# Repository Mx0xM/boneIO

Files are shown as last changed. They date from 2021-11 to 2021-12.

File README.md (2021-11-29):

# Project description

BonePic
BoneDiagram

`BoneIO` is a compact IO controller for home automation. Main features of this controller are

- Compact size (27x11x6)cm - 15 DIN modules
- DIN rail compatibility
- Low price
- Open HSP (See below)

# Technical details of v0.2

InputBoard

<<<<<<< HEAD

=======
>>>>>>> parent of 0485a88 (Update README.md)
- 52 digital inputs
- 7 analog to digital converters
- i2c
- rs485
- OLED display
- user switch
- 24V PSU input
- ADC VDD output
- 12-48V external PSU for digital inputs
- jumper to switch between internal and external PSU for inputs
- jumper to switch between vcc and gnd input control

RelayBoard24x16

- 24 relays (230V/16A) max current 5A* (10A* tinned traces, 16A* bridged 1,5 mm²) *everything needs to be verified
- temp sensor

RelayBoard32x5

- 32 relays (230V/5A)
- temp sensor

# Open HSP

`BoneIO` is an Open HSP initiative where everything is open on [GPL-3.0 License](https://github.com/maciejk1984/boneIO/blob/main/LICENSE)

- H (Hardware) stands for projects of electronic boards which you can print yourself
- S (Software) stands for ready to use firmware you can use on printed hardware
- P (Printables) stands for cases and other plastic elements you can print on a 3D printer and use with our hardware

With all elements in place, you can assemble a complete device. You can use it as-is or fork and modify it for your needs.

# Contribution

If you want to contribute to the project here are the rules:

1. First watch this short training: [How to use repo](https://www.youtube.com/watch?v=aY7B_t2UZy4)
2. When you have something to discuss first check out our [Team chat](https://discord.gg/PsrXEz9CBp)
3. When you have a specific problem/feature to report add new [issue](https://github.com/maciejk1984/boneIO/issues). `Remember to report single topic in one issue`. If you have complex topic try split it to more **precise** topics.
4. When you want change something in the repository use your **Fork** and make new **Pull Request** (See [Working with repository](.docs/github.md) (Polish))
5. You can also monitor our [Facebook group](https://www.facebook.com/groups/boneio)

# Documentation

- [Working with repository](.docs/github.md) (Polish)
- Youtube
  - [Project introduction](https://www.youtube.com/watch?v=_EIppBDZWvk) (Polish)
  - [Case introduction](https://www.youtube.com/watch?v=QjhMvNn7mG0) (Polish)
  - [Project status - 17.10.2021](https://www.youtube.com/watch?v=6J2S1L4vNMw) (Polish) 

# Photos of v0.1

Github

Github

Github

Github

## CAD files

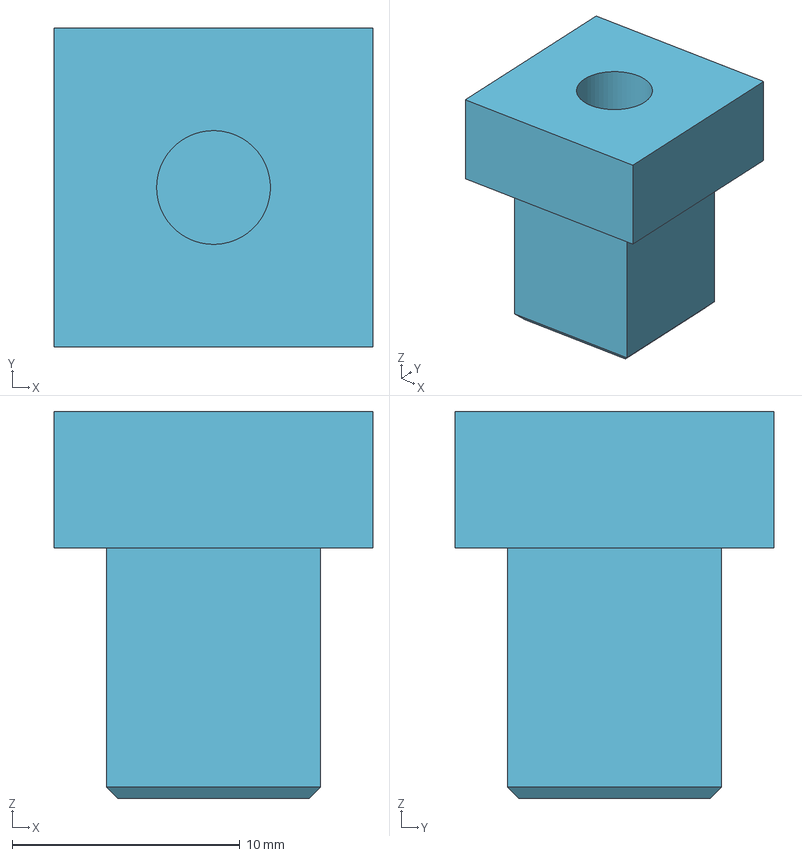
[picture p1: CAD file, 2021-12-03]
Case/boneIO-button.stp
14.0 x 14.0 x 17.0 mm

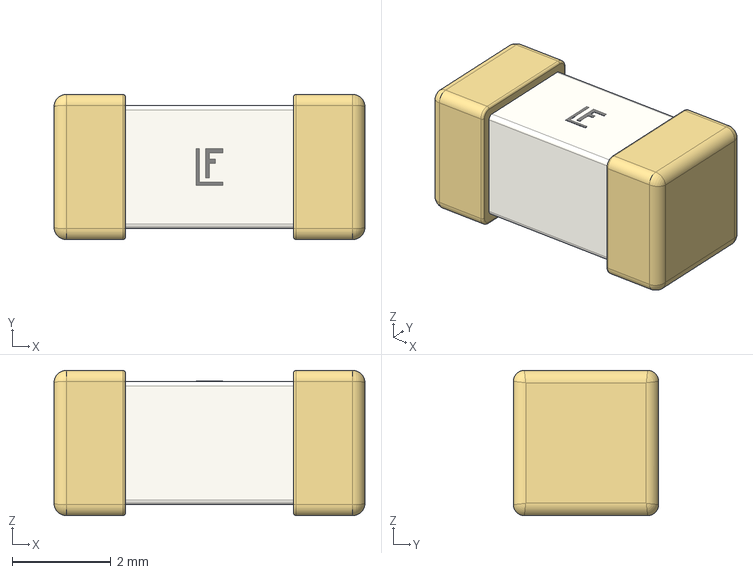
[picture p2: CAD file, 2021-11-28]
Circuit/boneIO - input board/3D_model/FUSE LTL-451.stp
6.30 x 2.94 x 2.94 mm

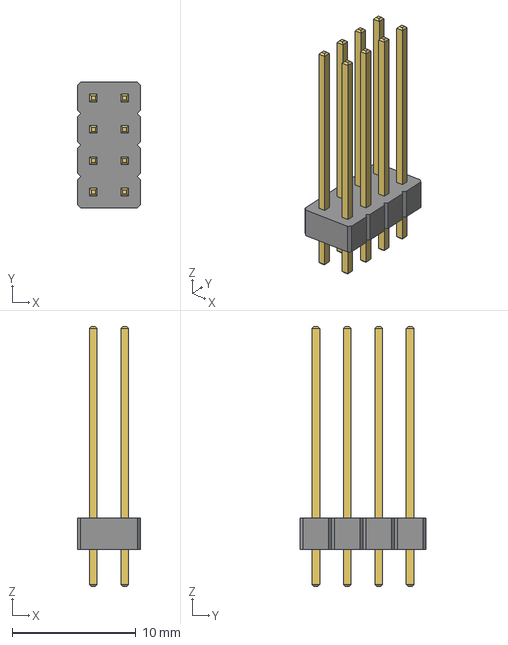
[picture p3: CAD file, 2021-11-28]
Circuit/boneIO - relay board 24x16A/3D_model/PH80DS-21.stp
5.08 x 10.2 x 21.0 mm

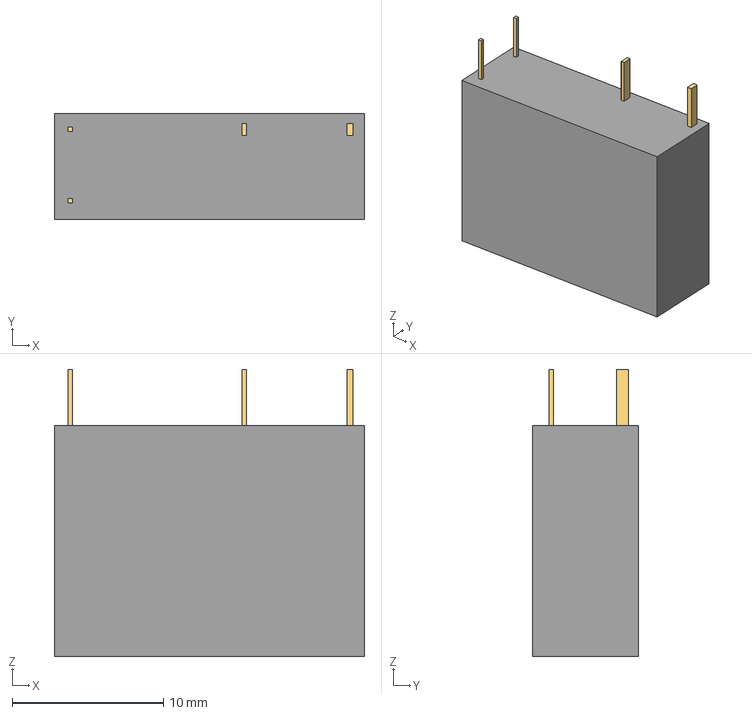
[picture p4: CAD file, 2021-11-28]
Circuit/boneIO - relay board 32x5A/HF46/HF46F.step
20.5 x 7.00 x 19.0 mm

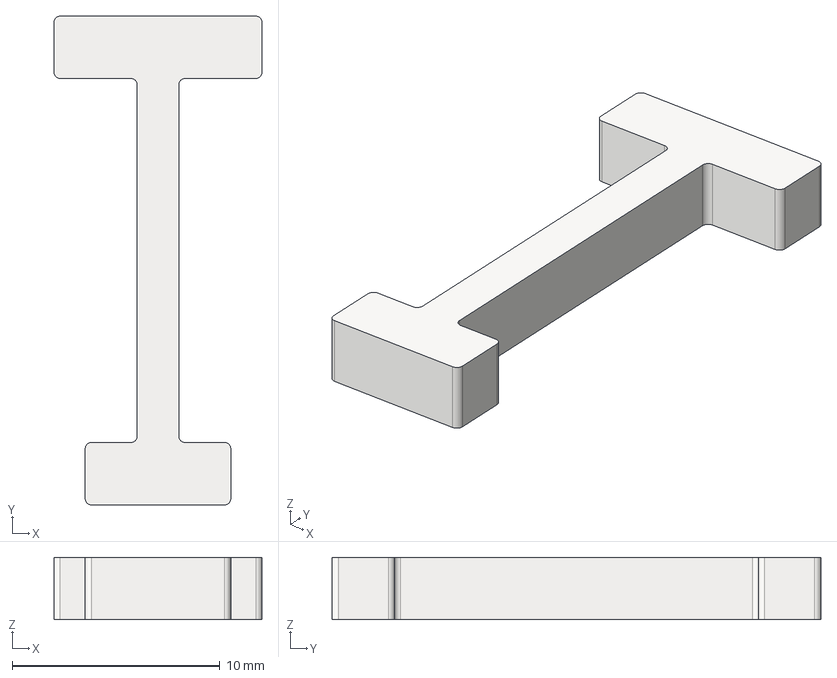
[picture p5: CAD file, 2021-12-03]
Case/boneIO-lock-pin.stp
10.0 x 23.5 x 3.00 mm

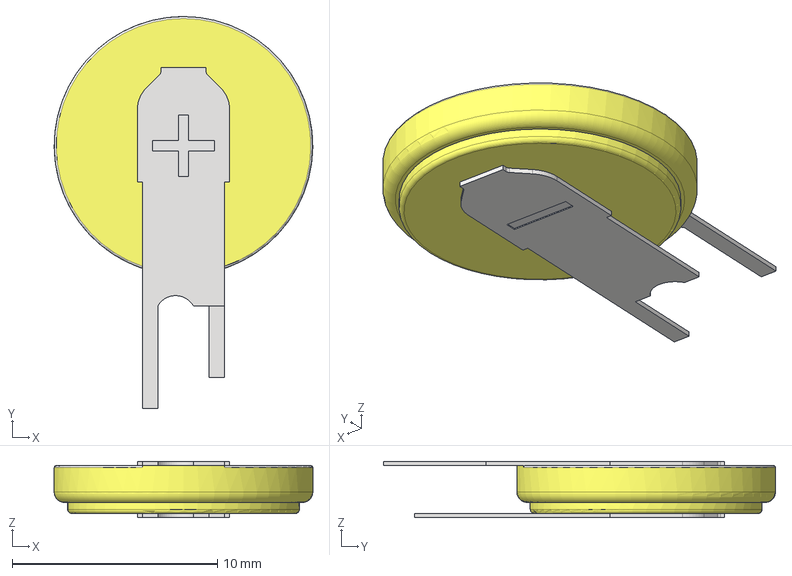
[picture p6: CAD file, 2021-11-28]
Circuit/boneIO - input board/3D_model/CR1220_VCNK.stp
12.6 x 19.1 x 2.74 mm

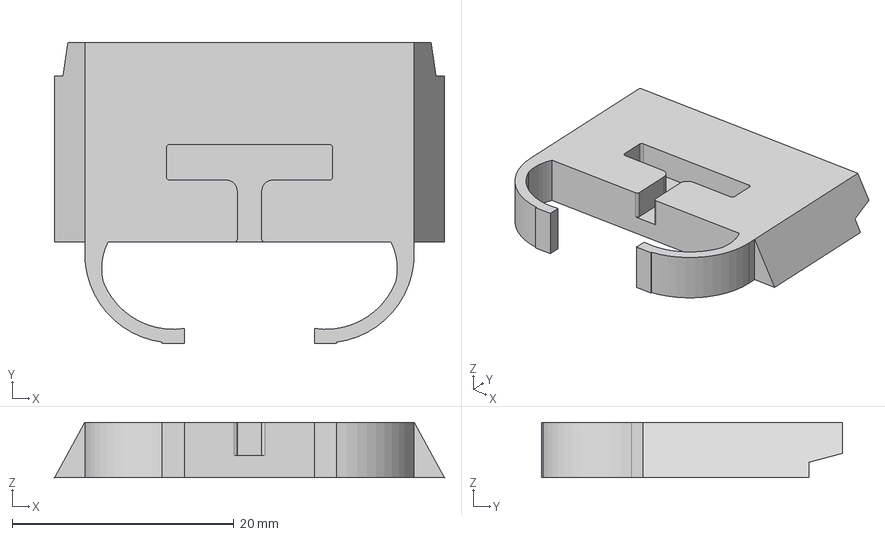
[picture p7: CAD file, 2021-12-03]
Case/boneIO-bottom-clips.stp
35.2 x 27.1 x 5.00 mm

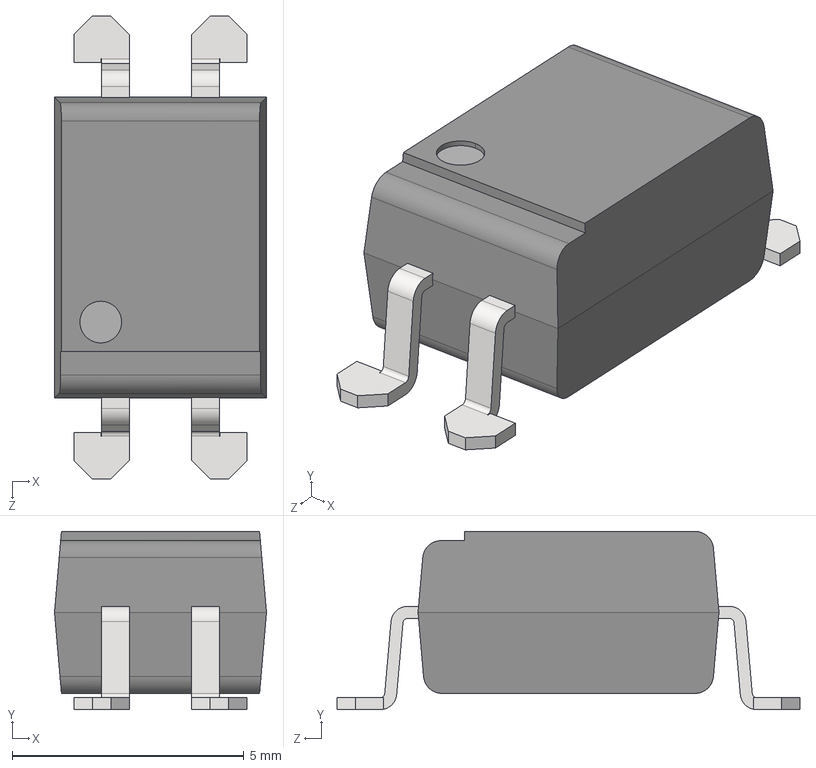
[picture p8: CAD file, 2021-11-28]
Circuit/boneIO - input board/3D_model/PC817.STEP
4.58 x 3.85 x 10.0 mm
PC817 Body
Gullwing Pin
Gullwing Pin_MIR
Gullwing Pin_MIR1
Gullwing Pin_MIR_MIR

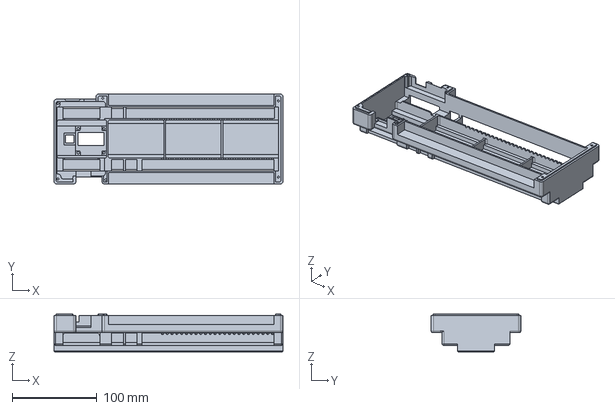
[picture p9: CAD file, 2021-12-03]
Case/boneIO-case-front.stp
270.0 x 106.0 x 44.5 mm

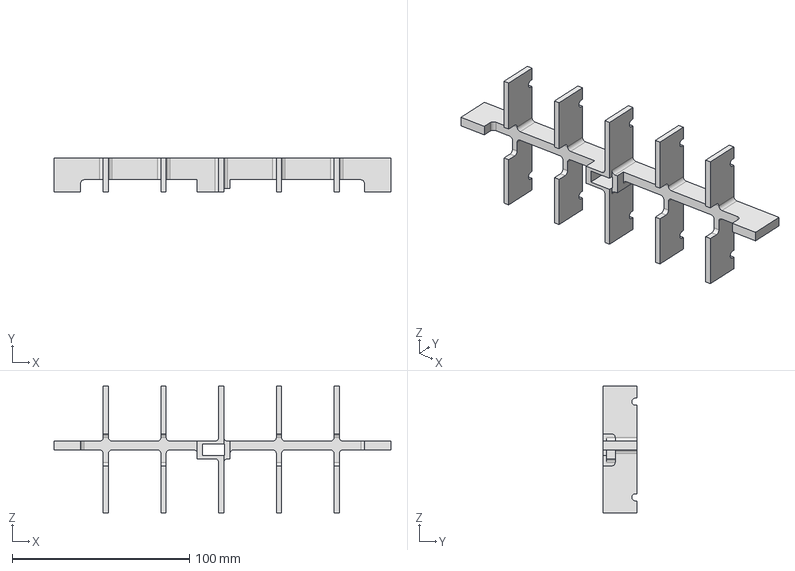
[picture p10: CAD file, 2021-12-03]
Case/boneIO-button-distance-relay-24x16A v0.2.stp
190.0 x 19.4 x 71.5 mm

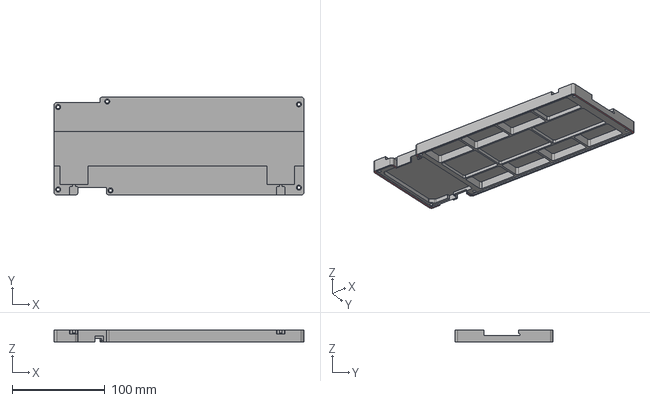
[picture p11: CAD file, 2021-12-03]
Case/boneIO-case-back.stp
270.0 x 106.0 x 12.5 mm

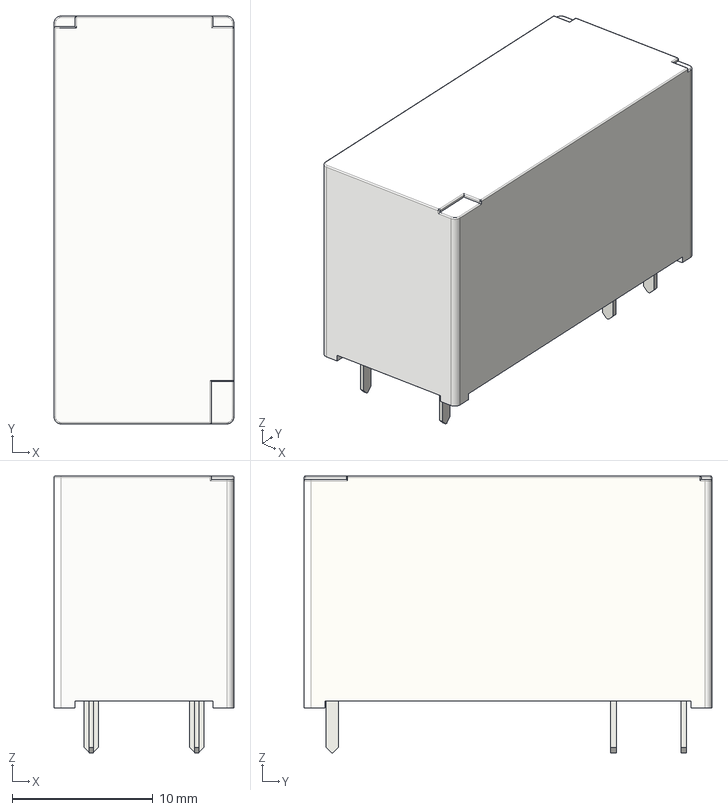
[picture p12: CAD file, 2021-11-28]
Circuit/boneIO - relay board 24x16A/3D_model/RM852011351005_1.step
12.8 x 29.0 x 19.7 mm

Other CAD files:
Case/boneIO-button-distance-relay-32x5A v0.2.stp
Case/boneIO-bottom-clips.stl
Case/boneIO-button-distance-relay-24x16A v0.2.stl
Case/boneIO-button-distance-relay-32x5A v0.2.stl
Case/boneIO-button.stl
Case/boneIO-case-back.stl
Case/boneIO-case-front.stl
Case/boneIO-lock-pin.stl

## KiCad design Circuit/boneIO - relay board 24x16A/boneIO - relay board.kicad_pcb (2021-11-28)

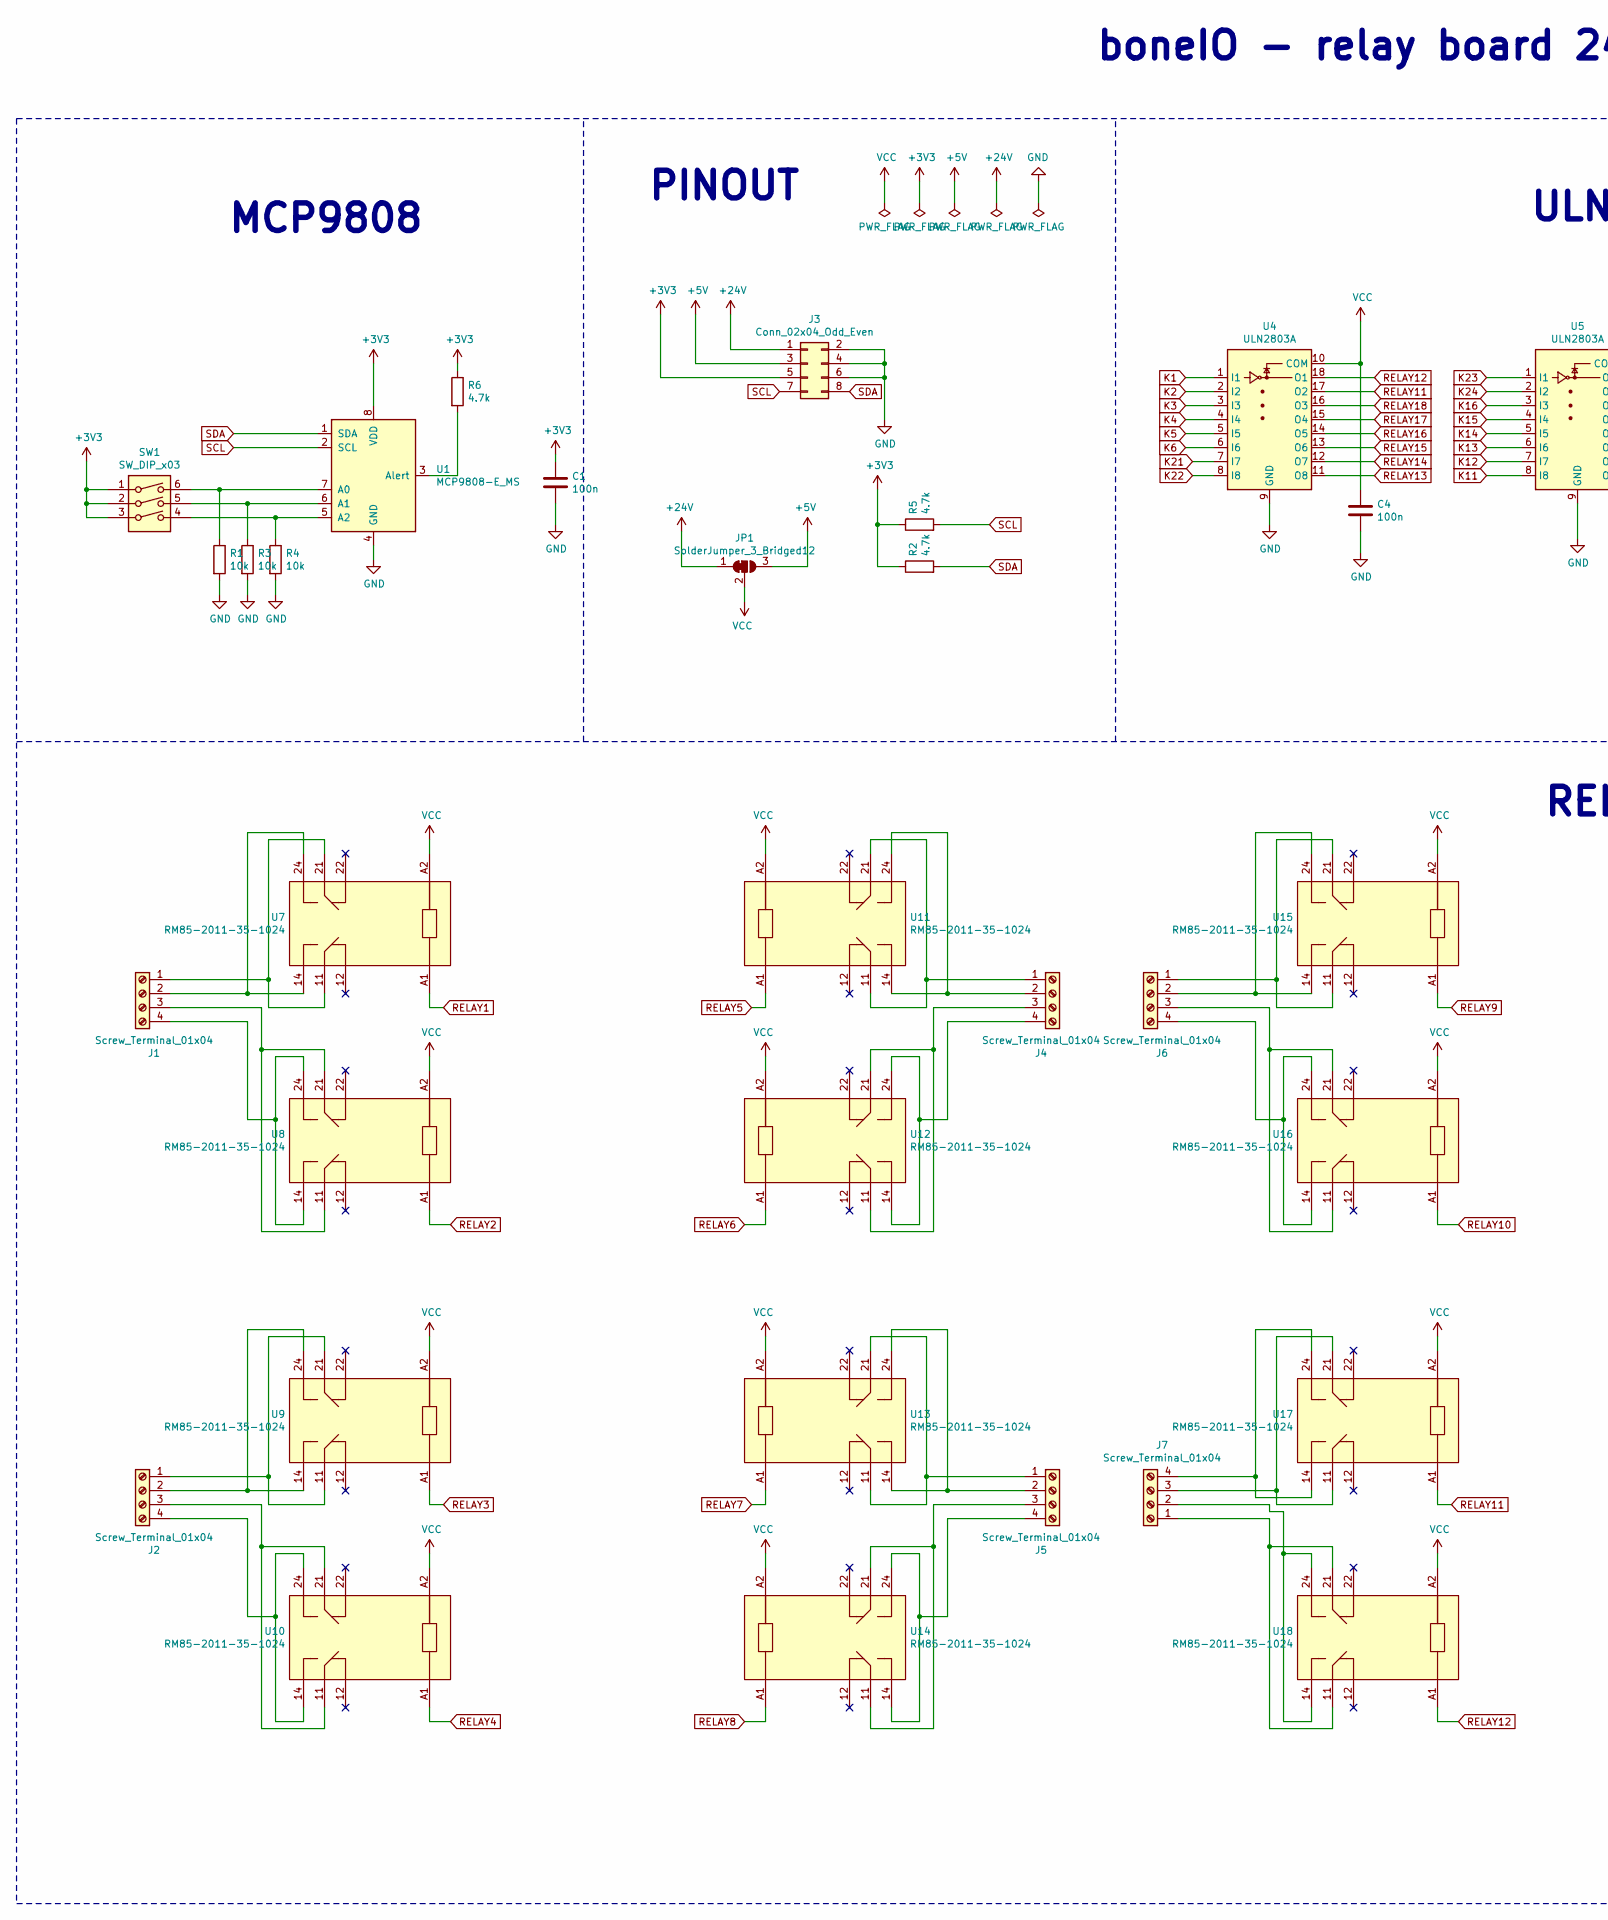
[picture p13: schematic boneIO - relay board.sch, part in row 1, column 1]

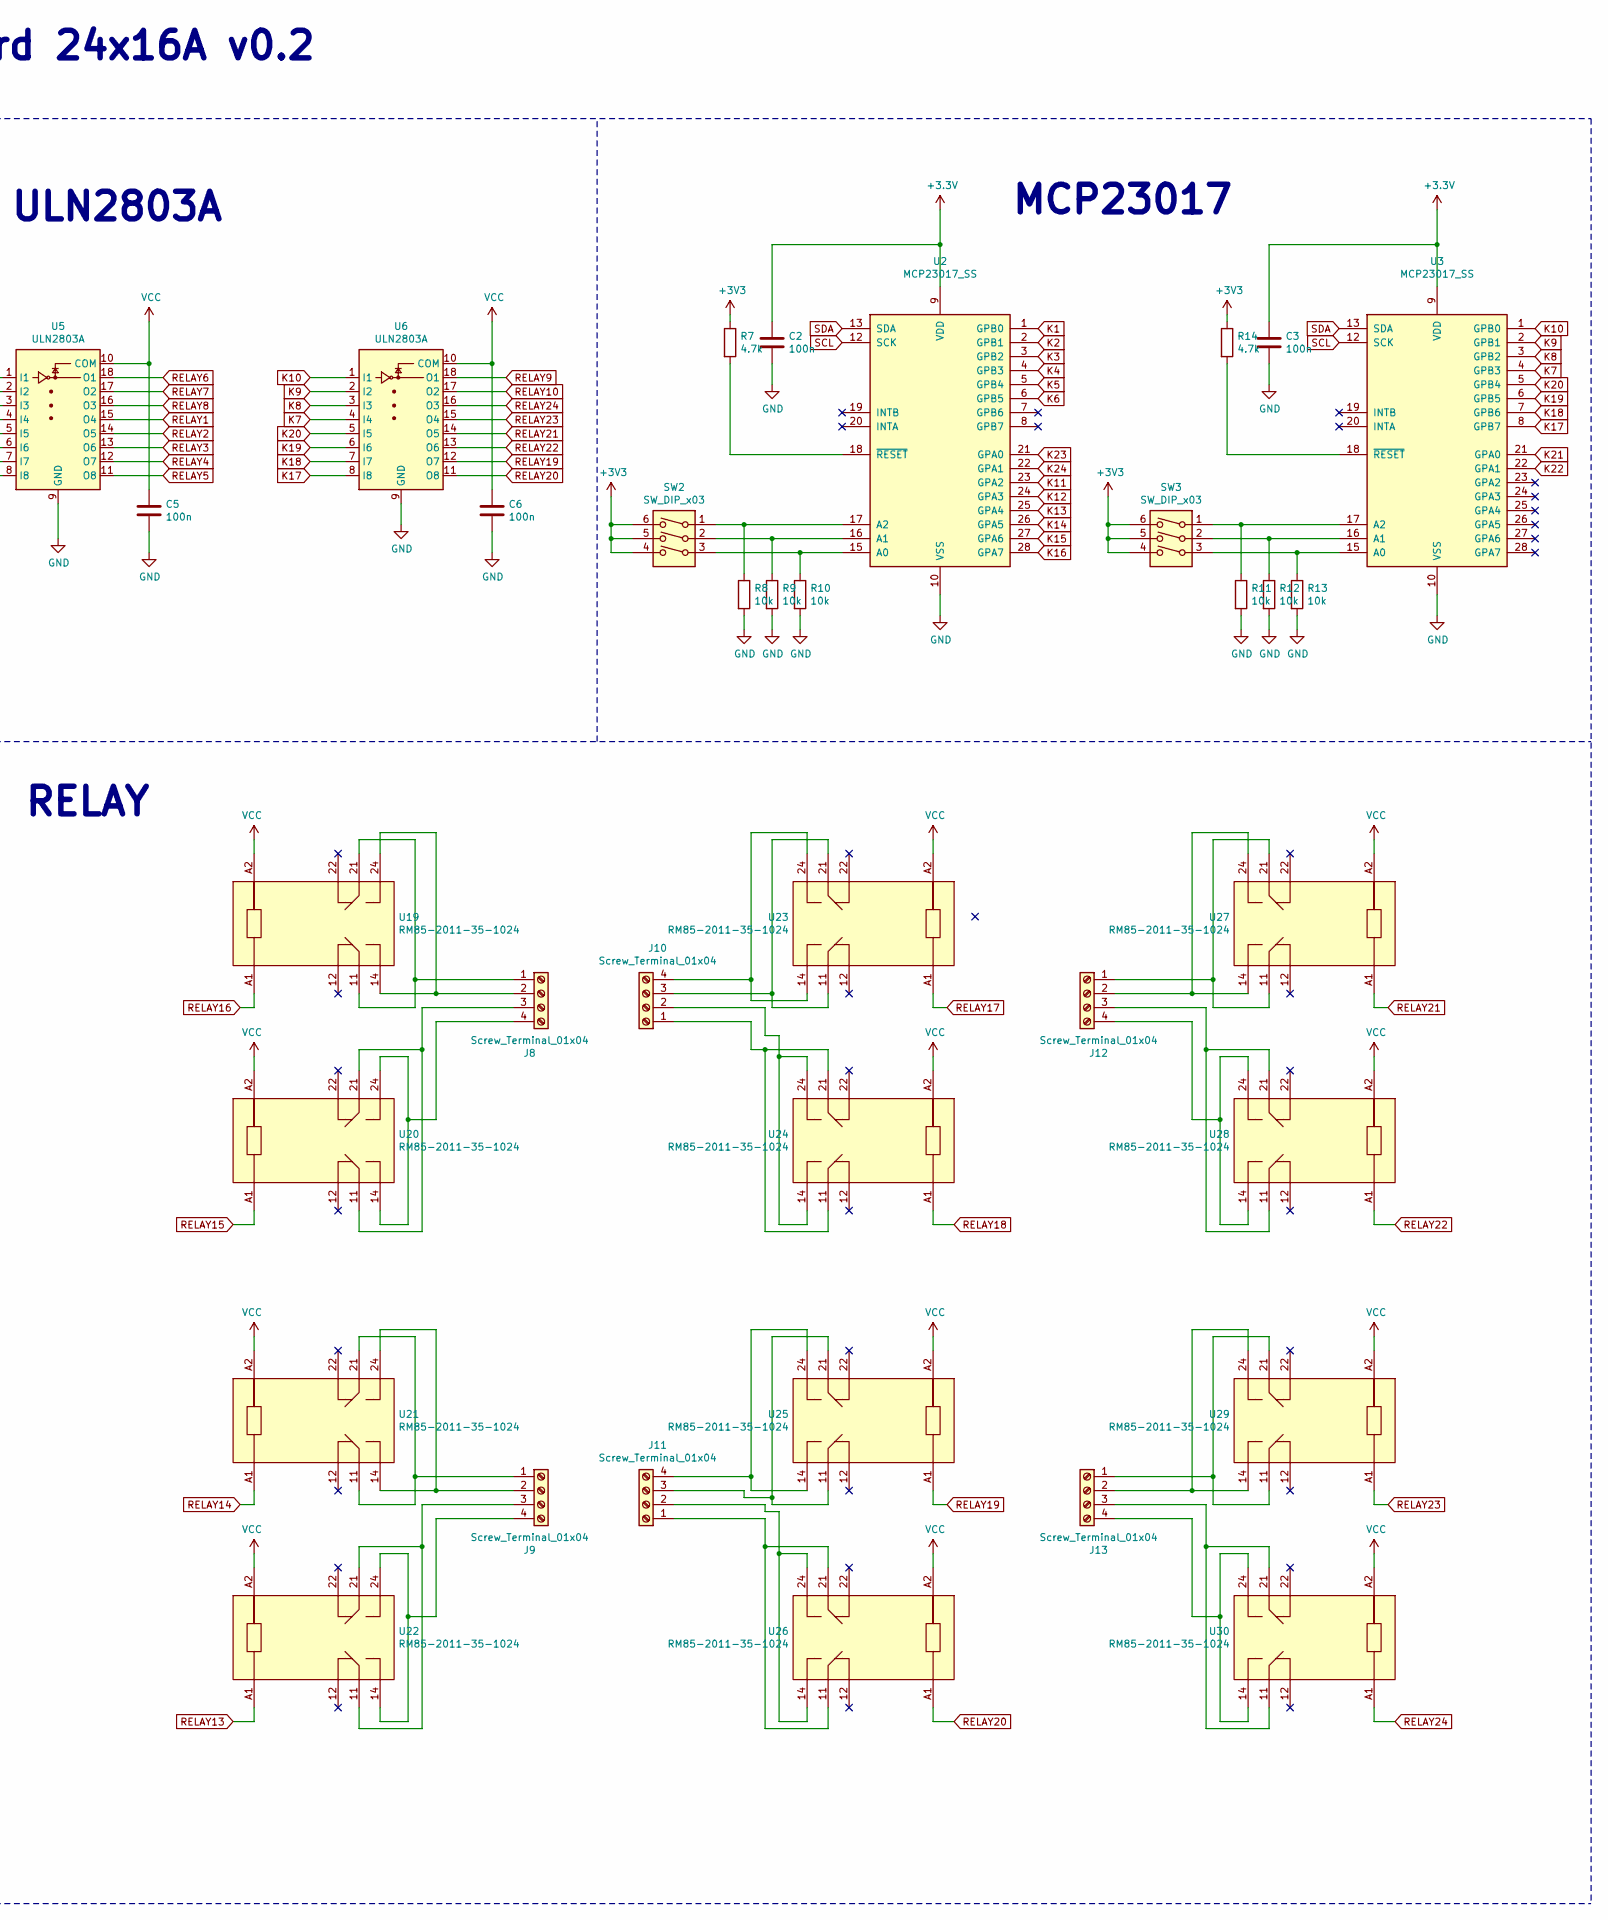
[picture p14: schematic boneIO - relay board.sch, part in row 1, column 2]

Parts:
C1, C2, C3, C4, C5, C6: 100n; C_0603_1608Metric
J1, J2, J4, J5, J6, J7, J8, J9, J10, J11, J12, J13: Screw_Terminal_01x04; PhoenixContact_GMSTBA_2,5_4-G_1x04_P7.50mm_Horizontal
J3: Conn_02x04_Odd_Even; PinHeader_2x04_P2.54mm_Vertical
JP1: SolderJumper_3_Bridged12; SolderJumper-3_P1.3mm_Bridged12_RoundedPad1.0x1.5mm
R1, R3, R4, R8, R9, R10, R11, R12, R13: 10k; R_0603_1608Metric
R2, R5, R6, R7, R14: 4.7k; R_0603_1608Metric
SW1, SW2, SW3: SW_DIP_x03; SW_DIP_SPSTx03_Slide_KingTek_DSHP03TJ_W5.25mm_P1.27mm_JPin
U1: MCP9808-E_MS; SOP65P490X110-8N
U2, U3: MCP23017_SS; SSOP-28_5.3x10.2mm_P0.65mm
U4, U5, U6: ULN2803A; SOIC-18W_7.5x11.6mm_P1.27mm
U7, U8, U9, U10, U11, U12, U13, U14, U15, U16, U17, U18, U19, U20, U21, U22, U23, U24, U25, U26, U27, U28, U29, U30: RM85-2011-35-1024; RM852011351024

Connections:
+5V: J3.3, JP1.3 (B)
+24V: J3.1, JP1.1 (A)
GND: C1.2, C2.2, C3.2, C4.2, C5.2, C6.2, J3.2, J3.4, J3.6, R1.2, R3.2, R4.2, R8.2, R9.2, R10.2, R11.2, R12.2, R13.2, U1.4 (GND), U2.10 (VSS), U3.10 (VSS), U4.9 (GND), U5.9 (GND), U6.9 (GND)
K1: U2.1 (GPB0), U4.1 (I1)
K2: U2.2 (GPB1), U4.2 (I2)
K3: U2.3 (GPB2), U4.3 (I3)
K4: U2.4 (GPB3), U4.4 (I4)
K5: U2.5 (GPB4), U4.5 (I5)
K6: U2.6 (GPB5), U4.6 (I6)
K7: U3.4 (GPB3), U6.4 (I4)
K8: U3.3 (GPB2), U6.3 (I3)
K9: U3.2 (GPB1), U6.2 (I2)
K10: U3.1 (GPB0), U6.1 (I1)
K11: U2.23 (GPA2), U5.8 (I8)
K12: U2.24 (GPA3), U5.7 (I7)
K13: U2.25 (GPA4), U5.6 (I6)
K14: U2.26 (GPA5), U5.5 (I5)
K15: U2.27 (GPA6), U5.4 (I4)
K16: U2.28 (GPA7), U5.3 (I3)
K17: U3.8 (GPB7), U6.8 (I8)
K18: U3.7 (GPB6), U6.7 (I7)
K19: U3.6 (GPB5), U6.6 (I6)
K20: U3.5 (GPB4), U6.5 (I5)
K21: U3.21 (GPA0), U4.7 (I7)
K22: U3.22 (GPA1), U4.8 (I8)
K23: U2.21 (GPA0), U5.1 (I1)
K24: U2.22 (GPA1), U5.2 (I2)
unnamed: J1.1, U7.11, U7.21
unnamed: J1.2, U7.14, U7.24
unnamed: J1.3, U8.11, U8.21
unnamed: J1.4, U8.14, U8.24
unnamed: J2.1, U9.11, U9.21
unnamed: J2.2, U9.14, U9.24
unnamed: J2.3, U10.11, U10.21
unnamed: J2.4, U10.14, U10.24
unnamed: J4.1, U11.11, U11.21
unnamed: J4.2, U11.14, U11.24
unnamed: J4.3, U12.11, U12.21
unnamed: J4.4, U12.14, U12.24
unnamed: J5.1, U13.11, U13.21
unnamed: J5.2, U13.14, U13.24
unnamed: J5.3, U14.11, U14.21
unnamed: J5.4, U14.14, U14.24
unnamed: J6.1, U15.11, U15.21
unnamed: J6.2, U15.14, U15.24
unnamed: J6.3, U16.11, U16.21
unnamed: J6.4, U16.14, U16.24
unnamed: J7.1, U18.11, U18.21
unnamed: J7.2, U18.14, U18.24
unnamed: J7.3, U17.11, U17.21
unnamed: J7.4, U17.14, U17.24
unnamed: J8.1, U19.11, U19.21
unnamed: J8.2, U19.14, U19.24
unnamed: J8.3, U20.11, U20.21
unnamed: J8.4, U20.14, U20.24
unnamed: J9.1, U21.11, U21.21
unnamed: J9.2, U21.14, U21.24
unnamed: J9.3, U22.11, U22.21
unnamed: J9.4, U22.14, U22.24
unnamed: J10.1, U24.11, U24.21
unnamed: J10.2, U24.14, U24.24
unnamed: J10.3, U23.11, U23.21
unnamed: J10.4, U23.14, U23.24
unnamed: J11.1, U26.11, U26.21
unnamed: J11.2, U26.14, U26.24
unnamed: J11.3, U25.11, U25.21
unnamed: J11.4, U25.14, U25.24
unnamed: J12.1, U27.11, U27.21
unnamed: J12.2, U27.14, U27.24
unnamed: J12.3, U28.11, U28.21
unnamed: J12.4, U28.14, U28.24
unnamed: J13.1, U29.11, U29.21
unnamed: J13.2, U29.14, U29.24
unnamed: J13.3, U30.11, U30.21
unnamed: J13.4, U30.14, U30.24
unnamed: R1.1, SW1.6, U1.7 (A0)
unnamed: R3.1, SW1.5, U1.6 (A1)
unnamed: R4.1, SW1.4, U1.5 (A2)
unnamed: R6.2, U1.3 (Alert)
unnamed: R7.2, U2.18 (~RESET~)
unnamed: R8.1, SW2.1, U2.17 (A2)
unnamed: R9.1, SW2.2, U2.16 (A1)
unnamed: R10.1, SW2.3, U2.15 (A0)
unnamed: R11.1, SW3.1, U3.17 (A2)
unnamed: R12.1, SW3.2, U3.16 (A1)
unnamed: R13.1, SW3.3, U3.15 (A0)
unnamed: R14.2, U3.18 (~RESET~)
RELAY1: U5.15 (O4), U7.A1
RELAY2: U5.14 (O5), U8.A1
RELAY3: U5.13 (O6), U9.A1
RELAY4: U5.12 (O7), U10.A1
RELAY5: U5.11 (O8), U11.A1
RELAY6: U5.18 (O1), U12.A1
RELAY7: U5.17 (O2), U13.A1
RELAY8: U5.16 (O3), U14.A1
RELAY9: U6.18 (O1), U15.A1
RELAY10: U6.17 (O2), U16.A1
RELAY11: U4.17 (O2), U17.A1
RELAY12: U4.18 (O1), U18.A1
RELAY13: U4.11 (O8), U22.A1
RELAY14: U4.12 (O7), U21.A1
RELAY15: U4.13 (O6), U20.A1
RELAY16: U4.14 (O5), U19.A1
RELAY17: U4.15 (O4), U23.A1
RELAY18: U4.16 (O3), U24.A1
RELAY19: U6.12 (O7), U25.A1
RELAY20: U6.11 (O8), U26.A1
RELAY21: U6.14 (O5), U27.A1
RELAY22: U6.13 (O6), U28.A1
RELAY23: U6.15 (O4), U29.A1
RELAY24: U6.16 (O3), U30.A1
SCL: J3.7, R5.2, U1.2 (SCL), U2.12 (SCK), U3.12 (SCK)
SDA: J3.8, R2.2, U1.1 (SDA), U2.13 (SDA), U3.13 (SDA)
VCC: C4.1, C5.1, C6.1, JP1.2 (C), U4.10 (COM), U5.10 (COM), U6.10 (COM), U7.A2, U8.A2, U9.A2, U10.A2, U11.A2, U12.A2, U13.A2, U14.A2, U15.A2, U16.A2, U17.A2, U18.A2, U19.A2, U20.A2, U21.A2, U22.A2, U23.A2, U24.A2, U25.A2, U26.A2, U27.A2, U28.A2, U29.A2, U30.A2

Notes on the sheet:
PINOUT
ULN2803A
RELAY
MCP9808
MCP23017
boneIO - relay board 24x16A v0.2

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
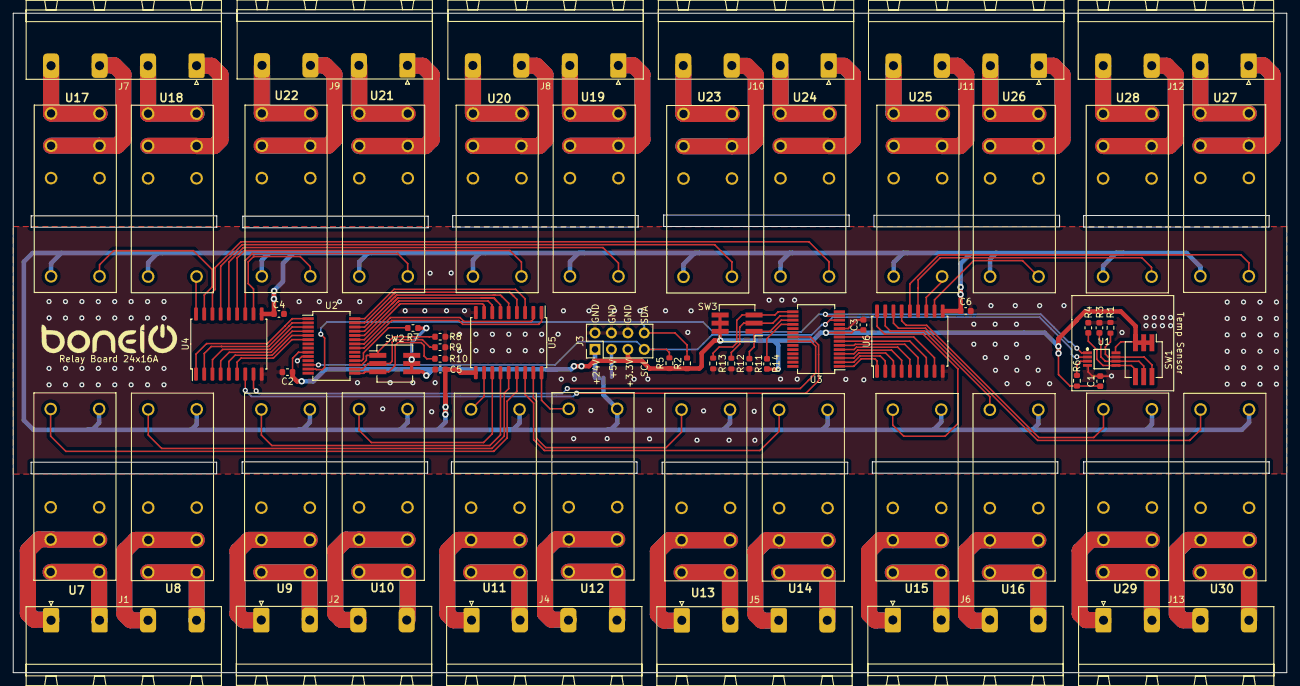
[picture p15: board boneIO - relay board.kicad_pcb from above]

Board: 2 copper layers, 197.0 x 102.0 mm, 67 parts (1 on the bottom side), 115 nets.

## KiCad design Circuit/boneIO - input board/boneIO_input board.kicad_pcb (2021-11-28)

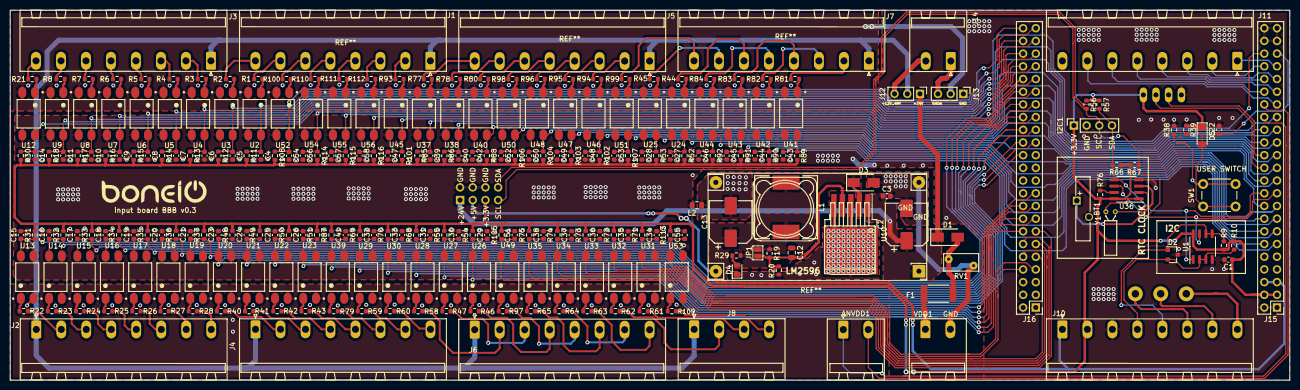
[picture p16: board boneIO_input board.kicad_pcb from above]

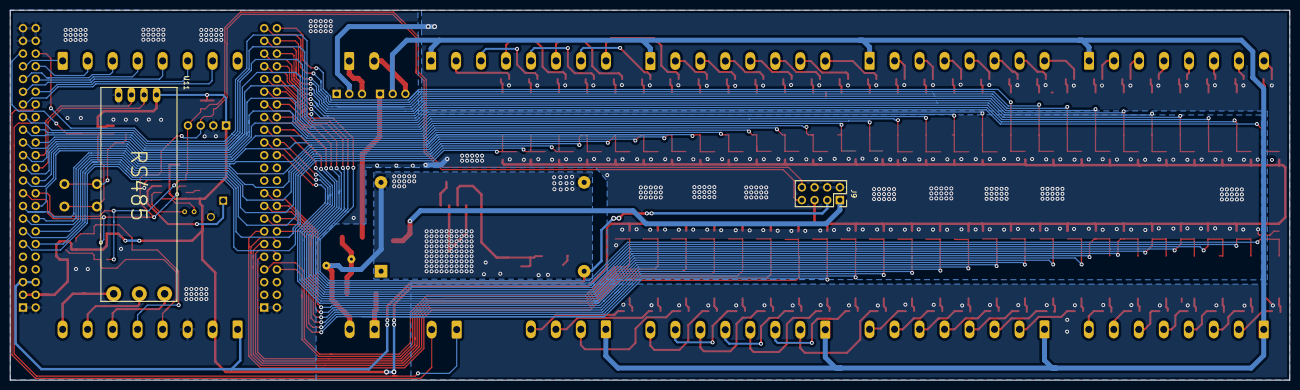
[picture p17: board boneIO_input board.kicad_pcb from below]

Board: 2 copper layers, 256.0 x 74.0 mm, 262 parts (2 on the bottom side), 194 nets.

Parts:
ANVDD1: Screw_Terminal_01x02; Phoenix_1x02_P5.00mm_Horizontal
BT1: Battery; Battery_Panasonic_CR1220-VCN_Vertical_CircularHoles
C1, C3, C4, C5, C6, C7, C8, C9, C10, C11, C14, C15, C16, C17, C18, C19, C20, C21, C22, C23, C24, C25, C26, C27, C28, C29, C30, C31, C32, C33, C34, C35, C36, C37, C38, C39, C40, C41, C42, C43, C44, C45, C46, C47, C48, C49, C50, C51, C52, C53, C54, C55, C56, C57, C58: 100n; C_0603_1608Metric
C2: 100uF/50V; CP_Elec_8x10
C12: 3n3; C_0805_2012Metric
C13: 220u/35V; CP_Elec_8x10
D1, D3: SS34; D_SMA
D2: BAT54A; SOT-23
D4: LED_RED; LED_0805_2012Metric
D5: 1N4148; D_MiniMELF
F1: Fuse_3A; Fuse_2512_6332Metric
I2C1: Conn_01x04; PinSocket_1x04_P2.54mm_Vertical
J1, J2, J3, J4, J5, J6, J7, J10, J11: Screw_Terminal_01x08; 8pin
J8: Screw_Terminal_01x04; Phoenix_1x04_P5.00mm_Horizontal
J9: Conn_02x04_Odd_Even; PinSocket_2x04_P2.54mm_Vertical
J12: ZW_VCC; PinHeader_1x03_P2.54mm_Vertical
J13: ZW_GND; PinHeader_1x03_P2.54mm_Vertical
J14: INNY ZASILACZ; Phoenix_1x02_P5.00mm_Horizontal
J15, J16: BeagleBone_Black_Header; PinHeader_2x23_P2.54mm_Vertical
JP1: 5V; SolderJumper-2_P1.3mm_Open_Pad1.0x1.5mm
L1: 4.7uH; L_12x12mm_H6mm
L2: BLM21PG221SN1D; L_0805_2012Metric
R1, R2, R3, R4, R5, R6, R7, R8, R21, R22, R23, R24, R25, R26, R27, R28, R39, R40, R41, R42, R43, R44, R45, R46, R47, R56, R57, R58, R59, R60, R61, R62, R63, R64, R65, R77, R78, R79, R80, R81, R82, R83, R84, R93, R94, R95, R96, R97, R98, R99, R100, R109, R110, R111, R112: 4.7k; R_0603_1608Metric
R9, R10: 680R; R_0603_1608Metric
R11, R12, R13, R14, R15, R16, R17, R18, R30, R31, R32, R33, R34, R35, R36, R37, R48, R49, R50, R51, R52, R53, R54, R55, R66, R67, R68, R69, R70, R71, R72, R73, R74, R75, R76, R85, R86, R87, R88, R89, R90, R91, R92, R101, R102, R103, R104, R105, R106, R107, R108, R113, R114, R115, R116: 10k; R_0603_1608Metric
R19: 3k; R_0603_1608Metric
R20: 1k; R_0603_1608Metric
R29: 1.2k; R_0603_1608Metric
R38: 330R; R_0603_1608Metric
RV1: 07D270K; RV_Disc_D7mm_W3.5mm_P5mm
SW1: SW_Push; SW_PUSH_6mm_H13mm
U1: P82B96; SO-8_3.9x4.9mm_P1.27mm
U2, U3, U4, U5, U6, U7, U8, U9, U12, U13, U14, U15, U16, U17, U18, U19, U20, U21, U22, U23, U24, U25, U26, U27, U28, U29, U30, U31, U32, U33, U34, U35, U37, U38, U39, U40, U41, U42, U43, U44, U45, U46, U47, U48, U49, U50, U51, U52, U53, U54, U55, U56: PC817X2NIP0F; SOT254P975X400-4N
U10: LM2596S-ADJ; TO-263-5_TabPin3
U11: RS485; RS485_moduleTTL
U36: DS1307Z+; SOIC-8_3.9x4.9mm_P1.27mm
VDD1: Screw_Terminal_01x02; Phoenix_1x02_P5.00mm_Horizontal
Y1: 32,788 MHz; Crystal_C26-LF_D2.1mm_L6.5mm_Horizontal

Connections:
+3V3: C1.1, D5.1, I2C1.1, J9.5, J10.2, J15.3, J15.4, R9.1, R10.1, R11.2, R12.2, R13.2, R14.2, R15.2, R16.2, R17.2, R18.2, R30.2, R31.2, R32.2, R33.2, R34.2, R35.2, R36.2, R37.2, R39.1, R48.2, R49.2, R50.2, R51.2, R52.2, R53.2, R54.2, R55.2, R56.1, R57.1, R66.1, R67.1, R68.2, R69.2, R70.2, R71.2, R72.2, R73.2, R74.2, R75.2, R76.1, R85.2, R86.2, R87.2, R88.2, R89.2, R90.2, R91.2, R92.2, R101.2, R102.2, R103.2, R104.2, R105.2, R106.2, R107.2, R108.2, R113.2, R114.2, R115.2, R116.2, U1.8, U11.1, U36.8
+5V: C12.1, C13.1, J9.3, J10.1, J15.5, J15.6, JP1.2, L1.2, R19.1, R29.1
+24V: C2.1, C3.1, D1.1, J9.1, J12.1, U10.1
+48V: J12.3, J14.2
A+: J10.6, U11.5
B-: J10.7, U11.6
Earth: C2.2, C3.2, C13.2, D3.2, D4.1, L2.1, R20.2, RV1.2, U10.3, U10.5, VDD1.2
GND: BT1.2, C1.2, C4.2, C5.2, C6.2, C7.2, C8.2, C9.2, C10.2, C11.2, C14.2, C15.2, C16.2, C17.2, C18.2, C19.2, C20.2, C21.2, C22.2, C23.2, C24.2, C25.2, C26.2, C27.2, C28.2, C29.2, C30.2, C31.2, C32.2, C33.2, C34.2, C35.2, C36.2, C37.2, C38.2, C39.2, C40.2, C41.2, C42.2, C43.2, C44.2, C45.2, C46.2, C47.2, C48.2, C49.2, C50.2, C51.2, C52.2, C53.2, C54.2, C55.2, C56.2, C57.2, C58.2, D2.3, I2C1.2, J9.2, J9.4, J9.6, J10.3, J13.1, J15.1, J15.2, J15.43, J15.44, J15.45, J15.46, J16.1, J16.2, L2.2, R38.2, U1.4, U2.3, U3.3, U4.3, U5.3, U6.3, U7.3, U8.3, U9.3, U11.4, U12.3, U13.3, U14.3, U15.3, U16.3, U17.3, U18.3, U19.3, U20.3, U21.3, U22.3, U23.3, U24.3, U25.3, U26.3, U27.3, U28.3, U29.3, U30.3, U31.3, U32.3, U33.3, U34.3, U35.3, U36.4, U37.3, U38.3, U39.3, U40.3, U41.3, U42.3, U43.3, U44.3, U45.3, U46.3, U47.3, U48.3, U49.3, U50.3, U51.3, U52.3, U53.3, U54.3, U55.3, U56.3
GND1: J13.3, J14.1
GNDA: J13.2, U2.2, U3.2, U4.2, U5.2, U6.2, U7.2, U8.2, U9.2, U12.2, U13.2, U14.2, U15.2, U16.2, U17.2, U18.2, U19.2, U20.2, U21.2, U22.2, U23.2, U24.2, U25.2, U26.2, U27.2, U28.2, U29.2, U30.2, U31.2, U32.2, U33.2, U34.2, U35.2, U37.2, U38.2, U39.2, U40.2, U41.2, U42.2, U43.2, U44.2, U45.2, U46.2, U47.2, U48.2, U49.2, U50.2, U51.2, U52.2, U53.2, U54.2, U55.2, U56.2
GNDD: J10.8, U11.7
GND_ADC: ANVDD1.2, J15.34
unnamed: BT1.1, U36.3
unnamed: C12.2, JP1.1, R19.2, R20.1, U10.4
unnamed: D1.2, F1.1, RV1.1
unnamed: D3.1, L1.1, U10.2
unnamed: D4.2, R29.2
unnamed: R1.1, U2.1
unnamed: R2.1, U3.1
unnamed: R3.1, U4.1
unnamed: R4.1, U5.1
unnamed: R5.1, U6.1
unnamed: R6.1, U7.1
unnamed: R7.1, U8.1
unnamed: R8.1, U9.1
unnamed: R21.1, U12.1
unnamed: R22.1, U13.1
unnamed: R23.1, U14.1
unnamed: R24.1, U15.1
unnamed: R25.1, U16.1
unnamed: R26.1, U17.1
unnamed: R27.1, U18.1
unnamed: R28.1, U19.1
unnamed: R38.1, SW1.1
unnamed: R40.1, U20.1
unnamed: R41.1, U21.1
unnamed: R42.1, U22.1
unnamed: R43.1, U23.1
unnamed: R44.1, U24.1
unnamed: R45.1, U25.1
unnamed: R46.1, U26.1
unnamed: R47.1, U27.1
unnamed: R58.1, U28.1
unnamed: R59.1, U29.1
unnamed: R60.1, U30.1
unnamed: R61.1, U31.1
unnamed: R62.1, U32.1
unnamed: R63.1, U33.1
unnamed: R64.1, U34.1
unnamed: R65.1, U35.1
unnamed: R76.2, U36.7
unnamed: R77.1, U37.1
unnamed: R78.1, U38.1
unnamed: R79.1, U39.1
unnamed: R80.1, U40.1
unnamed: R81.1, U41.1
unnamed: R82.1, U42.1
unnamed: R83.1, U43.1
unnamed: R84.1, U44.1
unnamed: R93.1, U45.1
unnamed: R94.1, U46.1
unnamed: R95.1, U47.1
unnamed: R96.1, U48.1
unnamed: R97.1, U49.1
unnamed: R98.1, U50.1
unnamed: R99.1, U51.1
unnamed: R100.1, U52.1
unnamed: R109.1, U53.1
unnamed: R110.1, U54.1
unnamed: R111.1, U55.1
unnamed: R112.1, U56.1
unnamed: U36.1, Y1.1
unnamed: U36.2, Y1.2
P8.07: C55.1, J16.7, R113.1, U53.4
P8.07_OUT: J8.4, R109.2
P8.08: C34.1, J16.8, R71.1, U31.4
P8.08_OUT: J8.3, R61.2
P8.09: C35.1, J16.9, R72.1, U32.4
P8.09_OUT: J8.2, R62.2
P8.10: C36.1, J16.10, R73.1, U33.4
P8.10_OUT: J6.8, R63.2
P8.11: C37.1, J16.11, R74.1, U34.4
P8.11_OUT: J6.7, R64.2
P8.12: C38.1, J16.12, R75.1, U35.4
P8.12_OUT: J6.6, R65.2
P8.13: C51.1, J16.13, R105.1, U49.4
P8.13_OUT: J6.5, R97.2
P8.14: C29.1, J16.14, R54.1, U26.4
P8.14_OUT: J6.4, R46.2
P8.15: C30.1, J16.15, R55.1, U27.4
P8.15_OUT: J6.3, R47.2
P8.16: C31.1, J16.16, R68.1, U28.4
P8.16_OUT: J6.2, R58.2
P8.17: C33.1, J16.17, R70.1, U30.4
P8.17_OUT: J4.8, R60.2
P8.18: C32.1, J16.18, R69.1, U29.4
P8.18_OUT: J4.7, R59.2
P8.19: C41.1, J16.19, R87.1, U39.4
P8.19_OUT: J4.6, R79.2
P8.26: C26.1, J16.26, R51.1, U23.4
P8.26_OUT: J4.5, R43.2
P8.27: C25.1, J16.27, R50.1, U22.4
P8.27_OUT: J4.4, R42.2
P8.28: C24.1, J16.28, R49.1, U21.4
P8.28_OUT: J4.3, R41.2
P8.29: C23.1, J16.29, R48.1, U20.4
P8.29_OUT: J4.2, R40.2
P8.30: C21.1, J16.30, R37.1, U19.4
P8.30_OUT: J2.8, R28.2
P8.31: C20.1, J16.31, R36.1, U18.4
P8.31_OUT: J2.7, R27.2
P8.32: C19.1, J16.32, R35.1, U17.4
P8.32_OUT: J2.6, R26.2
P8.33: C18.1, J16.33, R34.1, U16.4
P8.33_OUT: J2.5, R25.2
P8.34: C17.1, J16.34, R33.1, U15.4
P8.34_OUT: J2.4, R24.2
P8.35: C16.1, J16.35, R32.1, U14.4
P8.35_OUT: J2.3, R23.2
P8.36: C15.1, J16.36, R31.1, U13.4
P8.36_OUT: J2.2, R22.2
P8.37: C14.1, J16.37, R30.1, U12.4
P8.37_OUT: J3.8, R21.2
P8.38: C11.1, J16.38, R18.1, U9.4
P8.38_OUT: J3.7, R8.2
P8.39: C10.1, J16.39, R17.1, U8.4
P8.39_OUT: J3.6, R7.2
P8.40: C9.1, J16.40, R16.1, U7.4
P8.40_OUT: J3.5, R6.2
P8.41: C8.1, J16.41, R15.1, U6.4
P8.41_OUT: J3.4, R5.2
P8.42: C7.1, J16.42, R14.1, U5.4
P8.42_OUT: J3.3, R4.2
P8.43: C6.1, J16.43, R13.1, U4.4
P8.43_OUT: J3.2, R3.2
P8.44: C5.1, J16.44, R12.1, U3.4
P8.44_OUT: J1.8, R2.2
P8.45: C4.1, J16.45, R11.1, U2.4
P8.45_OUT: J1.7, R1.2
P8.46: C54.1, J16.46, R108.1, U52.4
P8.46_OUT: J1.6, R100.2
P9.11: C43.1, J15.11, R89.1, U41.4
P9.11_OUT: J7.2, R81.2
P9.12: C44.1, J15.12, R90.1, U42.4
P9.12_OUT: J7.3, R82.2
P9.13: C45.1, J15.13, R91.1, U43.4
P9.13_OUT: J7.4, R83.2
P9.14: C46.1, J15.14, R92.1, U44.4
P9.14_OUT: J7.5, R84.2
P9.15: C27.1, J15.15, R52.1, U24.4
P9.15_OUT: J7.6, R44.2
P9.16: C28.1, J15.16, R53.1, U25.4
P9.16_OUT: J7.7, R45.2
P9.17: C53.1, J15.17, R107.1, U51.4
P9.17_OUT: J7.8, R99.2
P9.18: C48.1, J15.18, R102.1, U46.4
P9.18_OUT: J5.2, R94.2
P9.21: C49.1, J15.21, R103.1, U47.4
P9.21_OUT: J5.3, R95.2
P9.22: C50.1, J15.22, R104.1, U48.4
P9.22_OUT: J5.4, R96.2
P9.23: C52.1, J15.23, R106.1, U50.4
P9.23_OUT: J5.5, R98.2
P9.25: C42.1, J15.25, R88.1, U40.4
P9.25_OUT: J5.6, R80.2
P9.27: C40.1, J15.27, R86.1, U38.4
P9.27_OUT: J5.7, R78.2
P9.28: C39.1, J15.28, R85.1, U37.4
P9.28_OUT: J5.8, R77.2
P9.29: C47.1, J15.29, R101.1, U45.4
P9.29_OUT: J1.2, R93.2
P9.30: C58.1, J15.30, R116.1, U56.4
P9.30_OUT: J1.3, R112.2
P9.31: C57.1, J15.31, R115.1, U55.4
P9.31_OUT: J1.4, R111.2
P9.33: J11.7, J15.33
P9.35: J11.5, J15.35
P9.36: J11.6, J15.36
P9.37: J11.3, J15.37
P9.38: J11.4, J15.38
P9.39: J11.1, J15.39
P9.40: J11.2, J15.40
P9.41: C22.1, D5.2, J15.41, R39.2, SW1.2
P9.42: C56.1, J15.42, R114.1, U54.4
P9.42_OUT: J1.5, R110.2
RX: J15.26, U11.3
SCL: I2C1.3, J9.7, J15.19, R56.2, R67.2, U1.7, U36.6
SCL_OUT: D2.1, J10.5, R9.2, U1.5, U1.6
SDA: I2C1.4, J9.8, J15.20, R57.2, R66.2, U1.1, U36.5
SDA_OUT: D2.2, J10.4, R10.2, U1.2, U1.3
TX: J15.24, U11.2
VCC: F1.2, VDD1.1
VDD: J1.1, J2.1, J3.1, J4.1, J5.1, J6.1, J7.1, J8.1, J12.2
VDD_ADC: ANVDD1.1, J15.32

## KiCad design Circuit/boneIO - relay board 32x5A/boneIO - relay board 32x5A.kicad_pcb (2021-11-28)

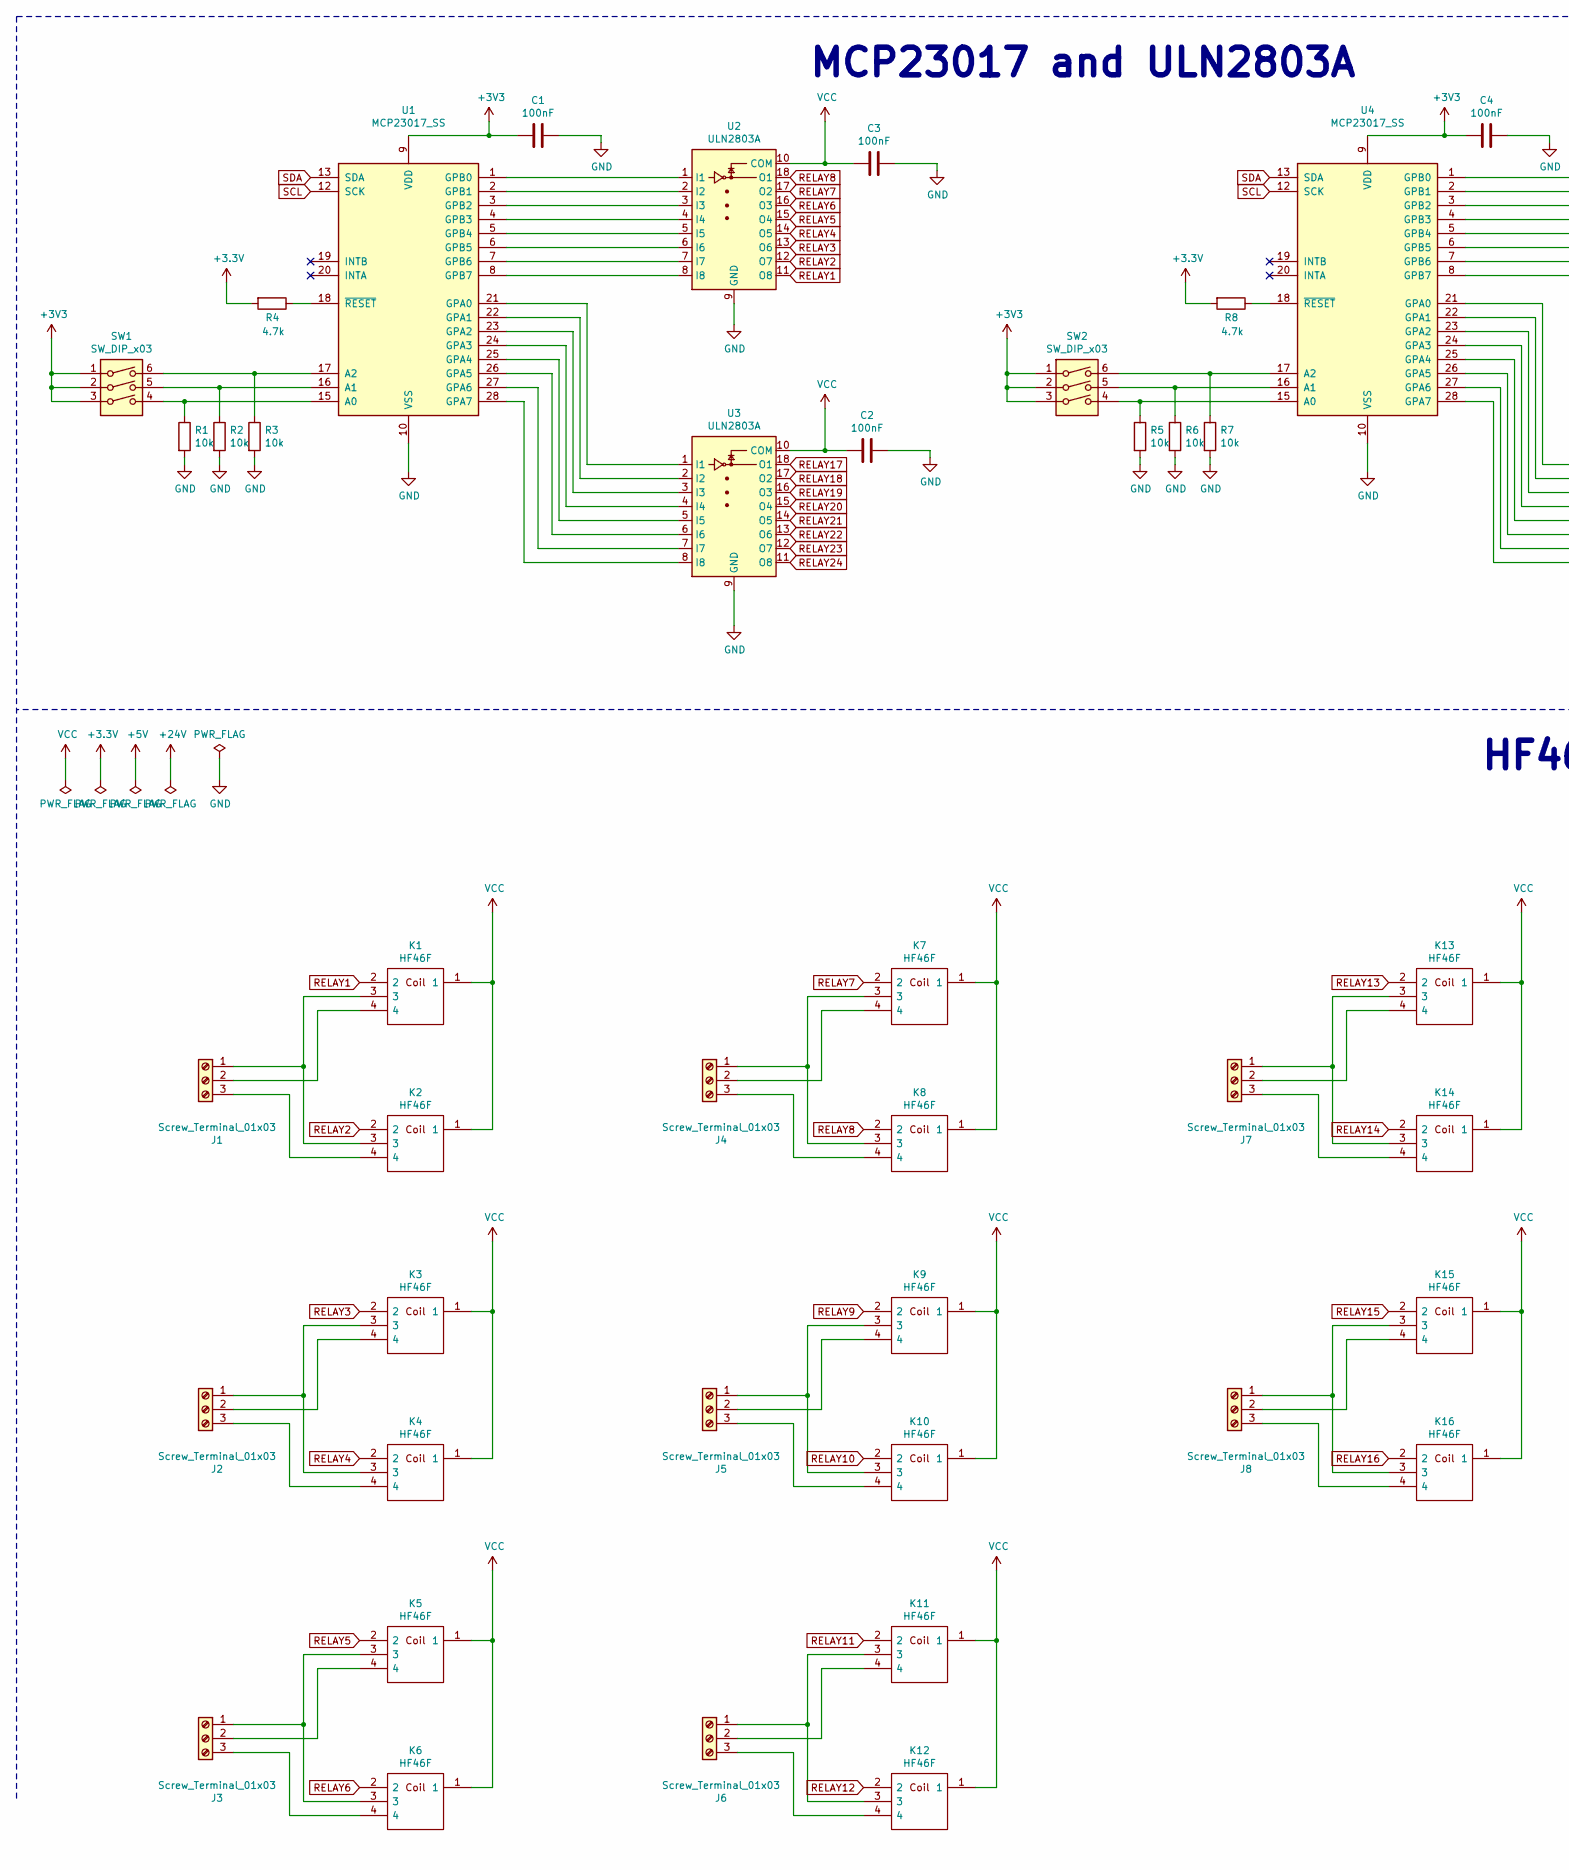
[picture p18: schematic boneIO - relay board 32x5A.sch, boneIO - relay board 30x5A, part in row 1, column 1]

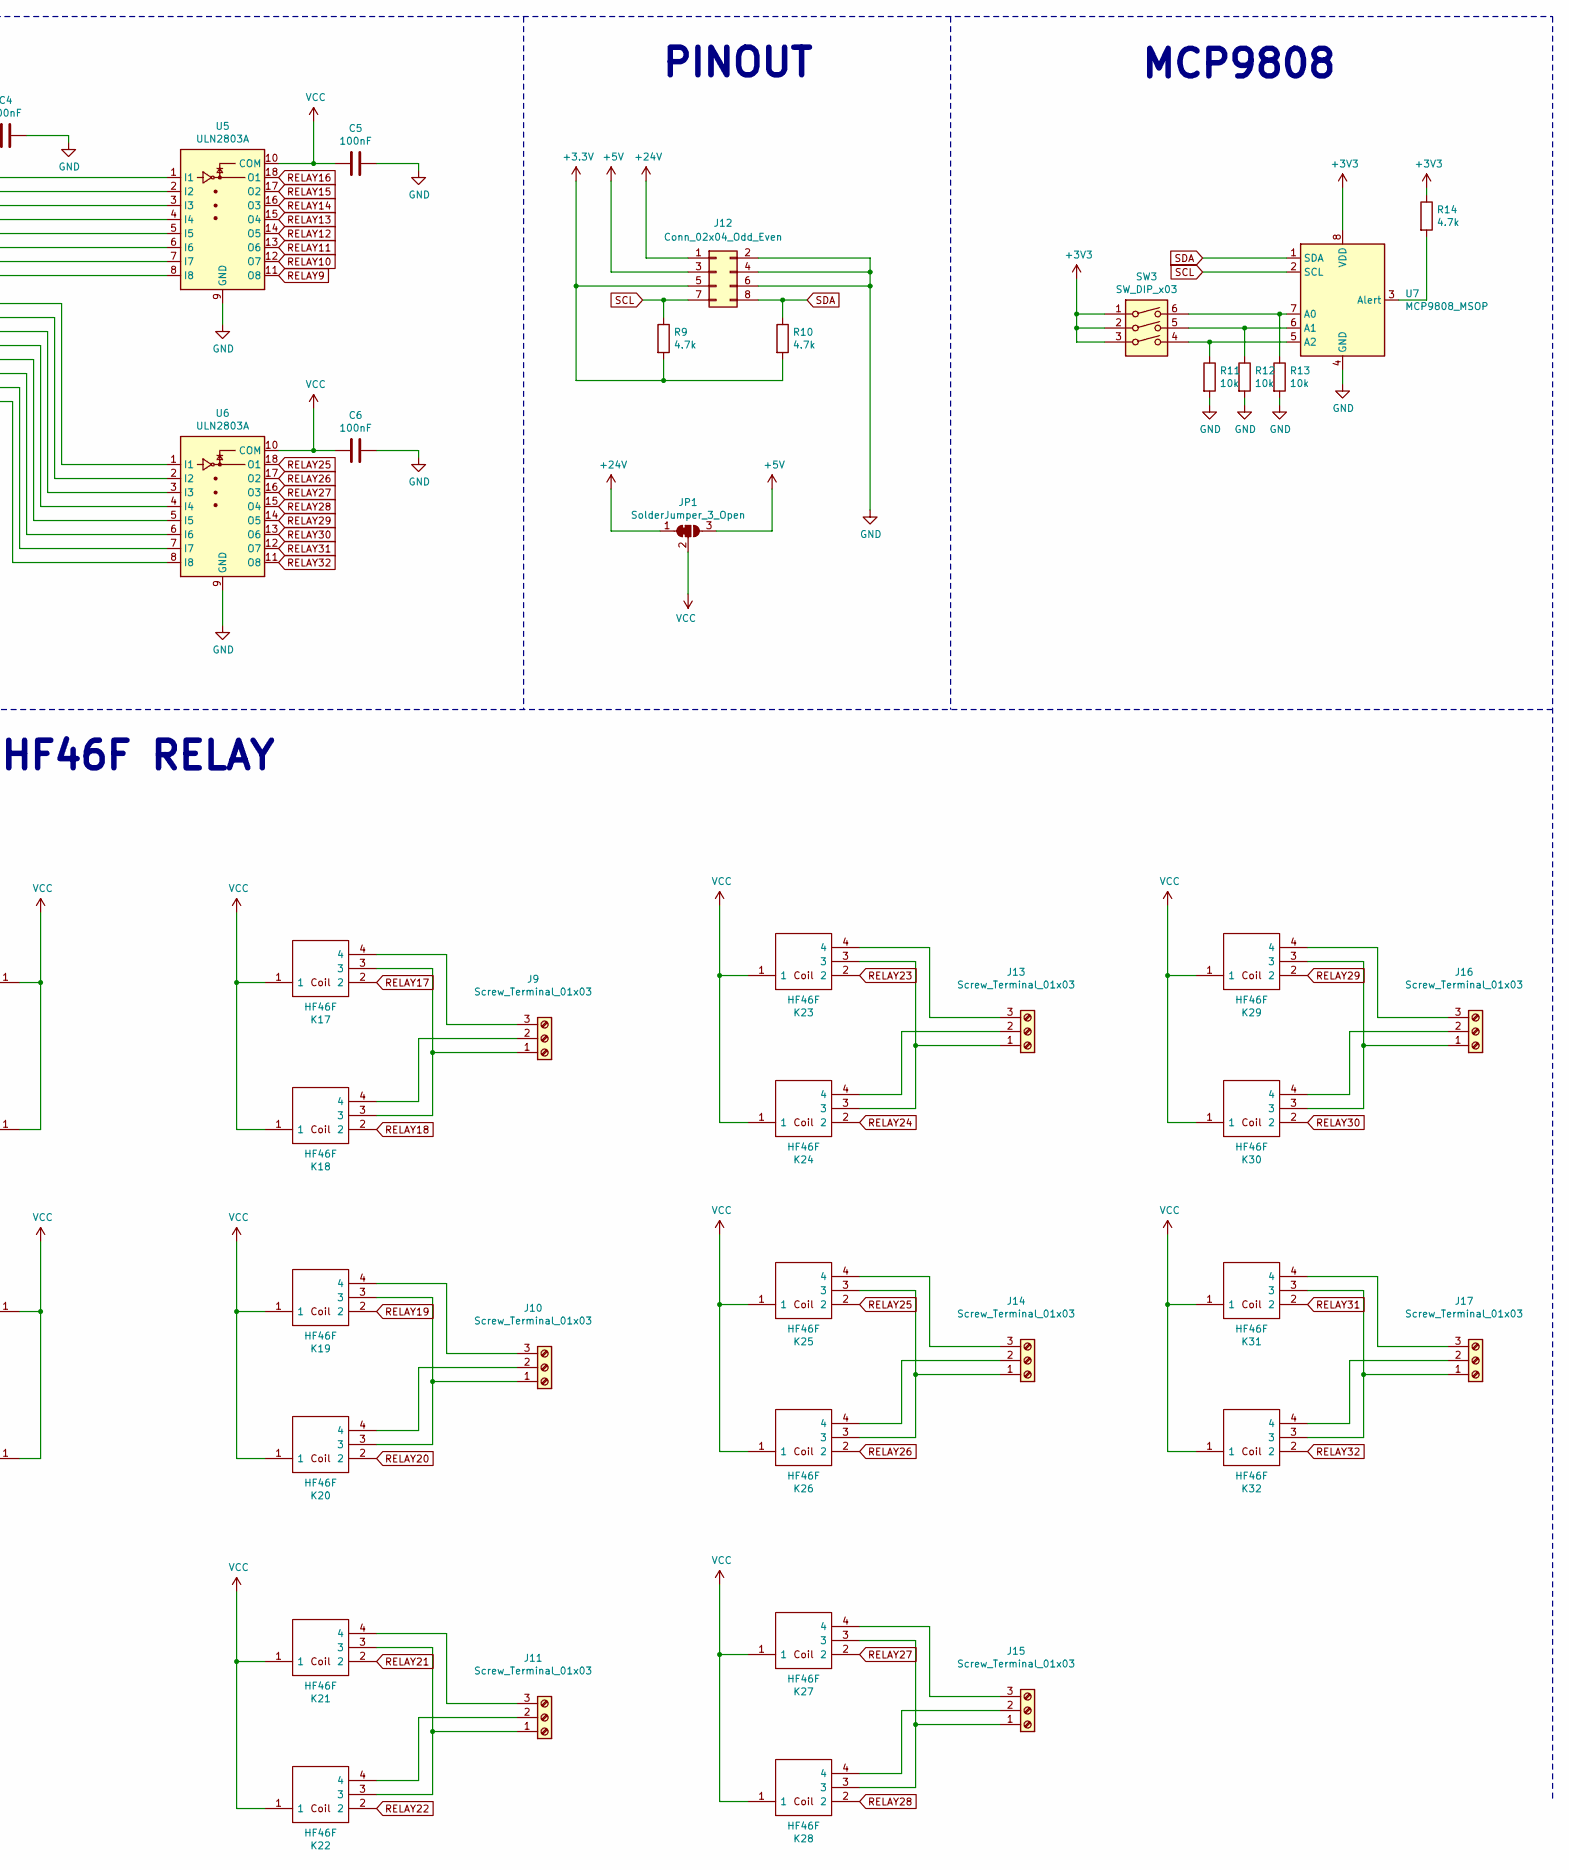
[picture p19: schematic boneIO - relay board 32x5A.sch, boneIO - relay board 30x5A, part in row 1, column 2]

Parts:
C1, C2, C3, C4, C5, C6: 100nF; C_0603_1608Metric
J1, J2, J3, J4, J5, J6, J7, J8, J9, J10, J11, J13, J14, J15, J16, J17: Screw_Terminal_01x03; PhoenixContact_GMSTBA_2,5_3-G_1x03_P7.50mm_Horizontal
J12: Conn_02x04_Odd_Even; PinHeader_2x04_P2.54mm_Vertical
JP1: SolderJumper_3_Open; SolderJumper-3_P1.3mm_Bridged12_RoundedPad1.0x1.5mm
K1, K2, K3, K4, K5, K6, K7, K8, K9, K10, K11, K12, K13, K14, K15, K16, K17, K18, K19, K20, K21, K22, K23, K24, K25, K26, K27, K28, K29, K30, K31, K32: HF46F; Manufacturer_Part_Number HF46F
R1, R2, R3, R5, R6, R7, R11, R12, R13: 10k; R_0603_1608Metric
R4, R8, R9, R10, R14: 4.7k; R_0603_1608Metric
SW1, SW2, SW3: SW_DIP_x03; SW_DIP_SPSTx03_Slide_KingTek_DSHP03TJ_W5.25mm_P1.27mm_JPin
U1, U4: MCP23017_SS; SSOP-28_5.3x10.2mm_P0.65mm
U2, U3, U5, U6: ULN2803A; SOIC-18W_7.5x11.6mm_P1.27mm
U7: MCP9808_MSOP; MSOP-8_3x3mm_P0.65mm

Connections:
+5V: J12.3, JP1.3 (B)
+24V: J12.1, JP1.1 (A)
GND: C1.1, C2.1, C3.1, C4.1, C5.1, C6.1, J12.2, J12.4, J12.6, R1.2, R2.2, R3.2, R5.2, R6.2, R7.2, R11.2, R12.2, R13.2, U1.10 (VSS), U2.9 (GND), U3.9 (GND), U4.10 (VSS), U5.9 (GND), U6.9 (GND), U7.4 (GND)
unnamed: J1.1, K1.3, K2.3
unnamed: J1.2, K1.4
unnamed: J1.3, K2.4
unnamed: J2.1, K3.3, K4.3
unnamed: J2.2, K3.4
unnamed: J2.3, K4.4
unnamed: J3.1, K5.3, K6.3
unnamed: J3.2, K5.4
unnamed: J3.3, K6.4
unnamed: J4.1, K7.3, K8.3
unnamed: J4.2, K7.4
unnamed: J4.3, K8.4
unnamed: J5.1, K9.3, K10.3
unnamed: J5.2, K9.4
unnamed: J5.3, K10.4
unnamed: J6.1, K11.3, K12.3
unnamed: J6.2, K11.4
unnamed: J6.3, K12.4
unnamed: J7.1, K13.3, K14.3
unnamed: J7.2, K13.4
unnamed: J7.3, K14.4
unnamed: J8.1, K15.3, K16.3
unnamed: J8.2, K15.4
unnamed: J8.3, K16.4
unnamed: J9.1, K17.3, K18.3
unnamed: J9.2, K18.4
unnamed: J9.3, K17.4
unnamed: J10.1, K19.3, K20.3
unnamed: J10.2, K20.4
unnamed: J10.3, K19.4
unnamed: J11.1, K21.3, K22.3
unnamed: J11.2, K22.4
unnamed: J11.3, K21.4
unnamed: J13.1, K23.3, K24.3
unnamed: J13.2, K24.4
unnamed: J13.3, K23.4
unnamed: J14.1, K25.3, K26.3
unnamed: J14.2, K26.4
unnamed: J14.3, K25.4
unnamed: J15.1, K27.3, K28.3
unnamed: J15.2, K28.4
unnamed: J15.3, K27.4
unnamed: J16.1, K29.3, K30.3
unnamed: J16.2, K30.4
unnamed: J16.3, K29.4
unnamed: J17.1, K31.3, K32.3
unnamed: J17.2, K32.4
unnamed: J17.3, K31.4
unnamed: R1.1, SW1.4, U1.15 (A0)
unnamed: R2.1, SW1.5, U1.16 (A1)
unnamed: R3.1, SW1.6, U1.17 (A2)
unnamed: R4.1, U1.18 (~RESET~)
unnamed: R5.1, SW2.4, U4.15 (A0)
unnamed: R6.1, SW2.5, U4.16 (A1)
unnamed: R7.1, SW2.6, U4.17 (A2)
unnamed: R8.1, U4.18 (~RESET~)
unnamed: R11.1, SW3.4, U7.5 (A2)
unnamed: R12.1, SW3.5, U7.6 (A1)
unnamed: R13.1, SW3.6, U7.7 (A0)
unnamed: R14.2, U7.3 (Alert)
unnamed: U1.1 (GPB0), U2.1 (I1)
unnamed: U1.2 (GPB1), U2.2 (I2)
unnamed: U1.3 (GPB2), U2.3 (I3)
unnamed: U1.4 (GPB3), U2.4 (I4)
unnamed: U1.5 (GPB4), U2.5 (I5)
unnamed: U1.6 (GPB5), U2.6 (I6)
unnamed: U1.7 (GPB6), U2.7 (I7)
unnamed: U1.8 (GPB7), U2.8 (I8)
unnamed: U1.21 (GPA0), U3.1 (I1)
unnamed: U1.22 (GPA1), U3.2 (I2)
unnamed: U1.23 (GPA2), U3.3 (I3)
unnamed: U1.24 (GPA3), U3.4 (I4)
unnamed: U1.25 (GPA4), U3.5 (I5)
unnamed: U1.26 (GPA5), U3.6 (I6)
unnamed: U1.27 (GPA6), U3.7 (I7)
unnamed: U1.28 (GPA7), U3.8 (I8)
unnamed: U4.1 (GPB0), U5.1 (I1)
unnamed: U4.2 (GPB1), U5.2 (I2)
unnamed: U4.3 (GPB2), U5.3 (I3)
unnamed: U4.4 (GPB3), U5.4 (I4)
unnamed: U4.5 (GPB4), U5.5 (I5)
unnamed: U4.6 (GPB5), U5.6 (I6)
unnamed: U4.7 (GPB6), U5.7 (I7)
unnamed: U4.8 (GPB7), U5.8 (I8)
unnamed: U4.21 (GPA0), U6.1 (I1)
unnamed: U4.22 (GPA1), U6.2 (I2)
unnamed: U4.23 (GPA2), U6.3 (I3)
unnamed: U4.24 (GPA3), U6.4 (I4)
unnamed: U4.25 (GPA4), U6.5 (I5)
unnamed: U4.26 (GPA5), U6.6 (I6)
unnamed: U4.27 (GPA6), U6.7 (I7)
unnamed: U4.28 (GPA7), U6.8 (I8)
RELAY1: K1.2, U2.11 (O8)
RELAY2: K2.2, U2.12 (O7)
RELAY3: K3.2, U2.13 (O6)
RELAY4: K4.2, U2.14 (O5)
RELAY5: K5.2, U2.15 (O4)
RELAY6: K6.2, U2.16 (O3)
RELAY7: K7.2, U2.17 (O2)
RELAY8: K8.2, U2.18 (O1)
RELAY9: K9.2, U5.11 (O8)
RELAY10: K10.2, U5.12 (O7)
RELAY11: K11.2, U5.13 (O6)
RELAY12: K12.2, U5.14 (O5)
RELAY13: K13.2, U5.15 (O4)
RELAY14: K14.2, U5.16 (O3)
RELAY15: K15.2, U5.17 (O2)
RELAY16: K16.2, U5.18 (O1)
RELAY17: K17.2, U3.18 (O1)
RELAY18: K18.2, U3.17 (O2)
RELAY19: K19.2, U3.16 (O3)
RELAY20: K20.2, U3.15 (O4)
RELAY21: K21.2, U3.14 (O5)
RELAY22: K22.2, U3.13 (O6)
RELAY23: K23.2, U3.12 (O7)
RELAY24: K24.2, U3.11 (O8)
RELAY25: K25.2, U6.18 (O1)
RELAY26: K26.2, U6.17 (O2)
RELAY27: K27.2, U6.16 (O3)
RELAY28: K28.2, U6.15 (O4)
RELAY29: K29.2, U6.14 (O5)
RELAY30: K30.2, U6.13 (O6)
RELAY31: K31.2, U6.12 (O7)
RELAY32: K32.2, U6.11 (O8)
SCL: J12.7, R9.1, U1.12 (SCK), U4.12 (SCK), U7.2 (SCL)
SDA: J12.8, R10.1, U1.13 (SDA), U4.13 (SDA), U7.1 (SDA)
VCC: C2.2, C3.2, C5.2, C6.2, JP1.2 (C), K1.1, K2.1, K3.1, K4.1, K5.1, K6.1, K7.1, K8.1, K9.1, K10.1, K11.1, K12.1, K13.1, K14.1, K15.1, K16.1, K17.1, K18.1, K19.1, K20.1, K21.1, K22.1, K23.1, K24.1, K25.1, K26.1, K27.1, K28.1, K29.1, K30.1, K31.1, K32.1, U2.10 (COM), U3.10 (COM), U5.10 (COM), U6.10 (COM)

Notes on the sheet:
PINOUT
MCP23017 and ULN2803A
HF46F RELAY
MCP9808

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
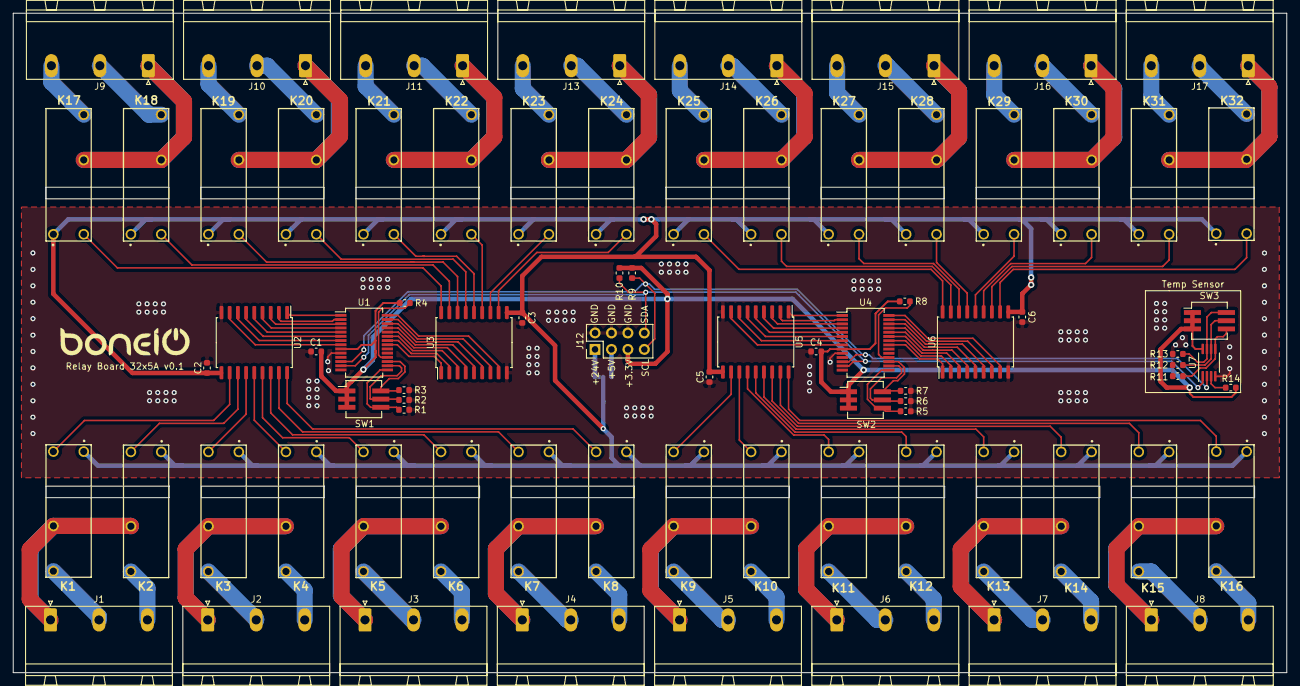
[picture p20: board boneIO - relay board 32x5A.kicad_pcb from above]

Board: 2 copper layers, 197.0 x 102.0 mm, 80 parts (1 on the bottom side), 131 nets.

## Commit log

2021-11-28 Dodano pogłębienie na kondensatory
    [boneIO-case-front.stp]
2021-12-03 Aktualizacja 03.12.21
    -Usunięto kolizję
    -Dodano miejsce na rezystory
    -Odchudzono górną ściankę
    -Odchudzono boczną ściankę
    -Poprawiono dystanse dla płytek 24x16A i 32x5A
    [boneIO-bottom-clips.stl, boneIO-bottom-clips.stp, boneIO-button-distance-relay-24x16A v0.2.stl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]
